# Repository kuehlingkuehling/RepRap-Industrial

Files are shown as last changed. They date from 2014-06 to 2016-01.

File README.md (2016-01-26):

# Kühling&Kühling RepRap Industrial

These are the OpenSCAD source files for the Kühling&Kühling RepRap Industrial 3D printer.
Based on the principle of the [RepRap Project](http://reprap.org) this 3D printer design is developed by

* Jonas Kühling <mail@jonaskuehling.de>
* Simon Kühling <mail@simonkuehling.de>

All information about the machine, build instructions and such will be published at
[http://kuehlingkuehling.de](http://kuehlingkuehling.de)
as soon as they are finished.

## Current Revision

1.4.1-dev

## License

This OpenSCAD code and its rendered 3D models are licensed unter the Creative Commons Attribution-ShareAlike 4.0 International License (CC BY-SA 4.0).
[https://creativecommons.org/licenses/by-sa/4.0/](https://creativecommons.org/licenses/by-sa/4.0/)

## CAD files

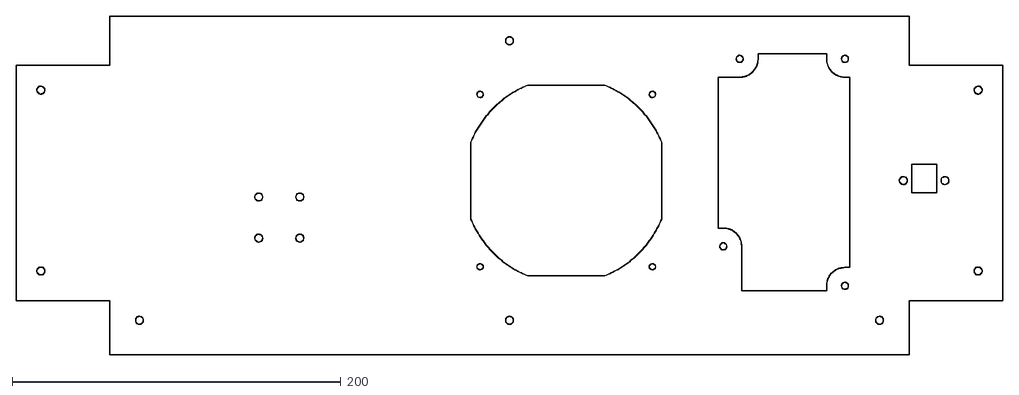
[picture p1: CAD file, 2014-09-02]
DXF/frame-enclosure_base-back.dxf
600.0 x 206.0

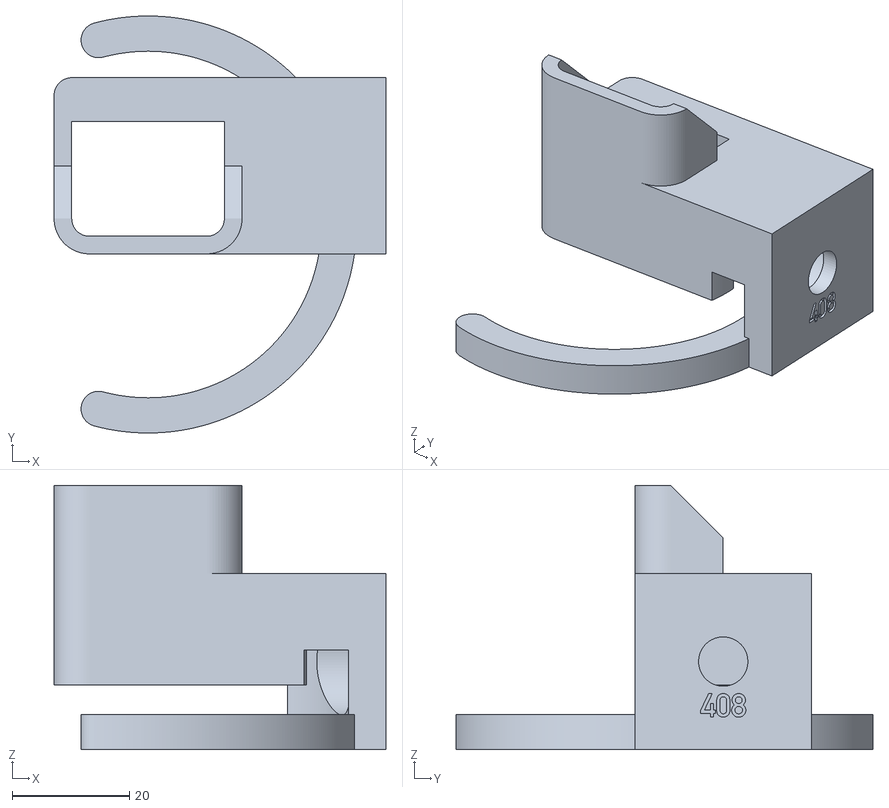
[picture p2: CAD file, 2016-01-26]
STL/408___wiper.stl
56.5 x 71.0 x 45.0

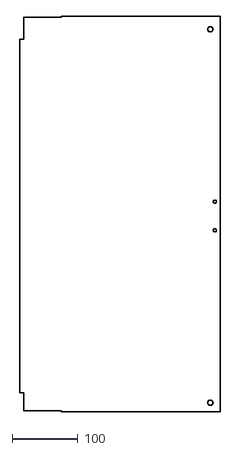
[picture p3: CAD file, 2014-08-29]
DXF/frame-enclosure_chamber-door-left.dxf
305.5 x 603.0

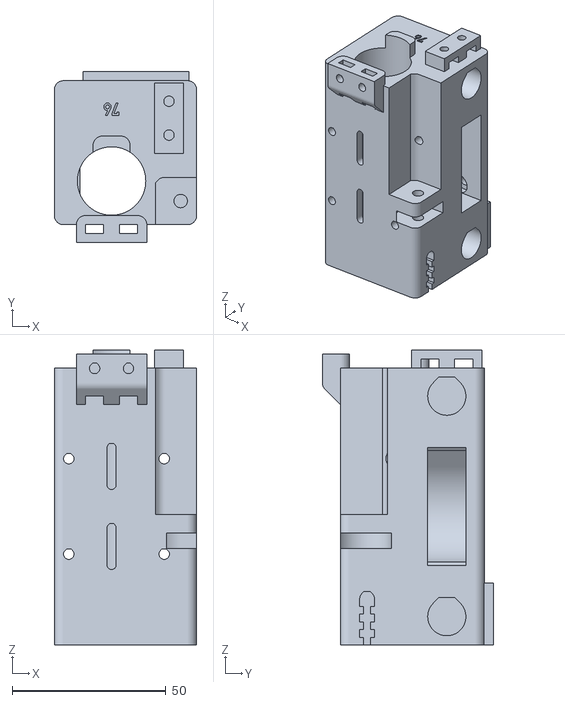
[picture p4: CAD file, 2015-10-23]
STL/76___x-end_motor.stl
46.2 x 55.6 x 95.8

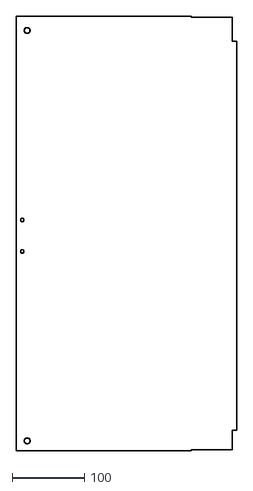
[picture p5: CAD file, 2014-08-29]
DXF/frame-enclosure_chamber-door-right.dxf
305.5 x 603.0

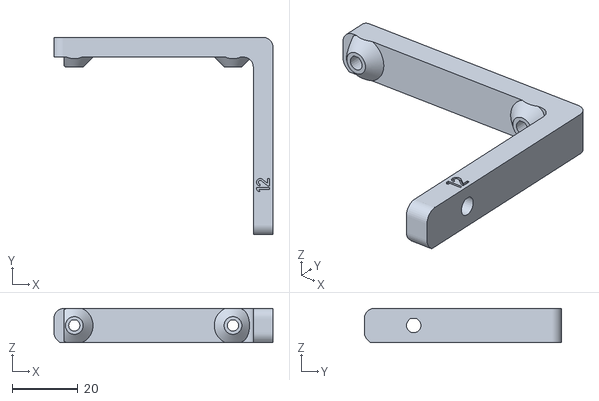
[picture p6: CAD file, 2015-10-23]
STL/12___pcb-mount_beagleboneblack-left.stl
66.6 x 60.0 x 10.4

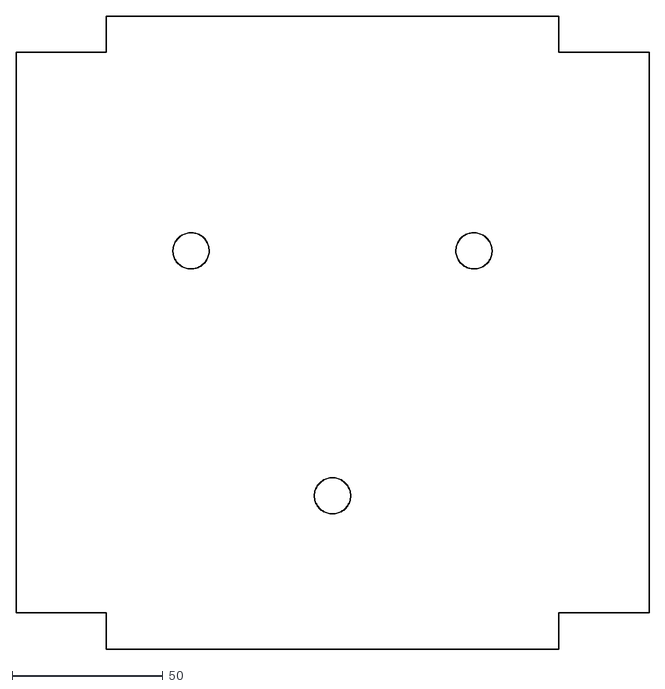
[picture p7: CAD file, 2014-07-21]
DXF/bed-siliconeheater.dxf
210.0 x 210.0

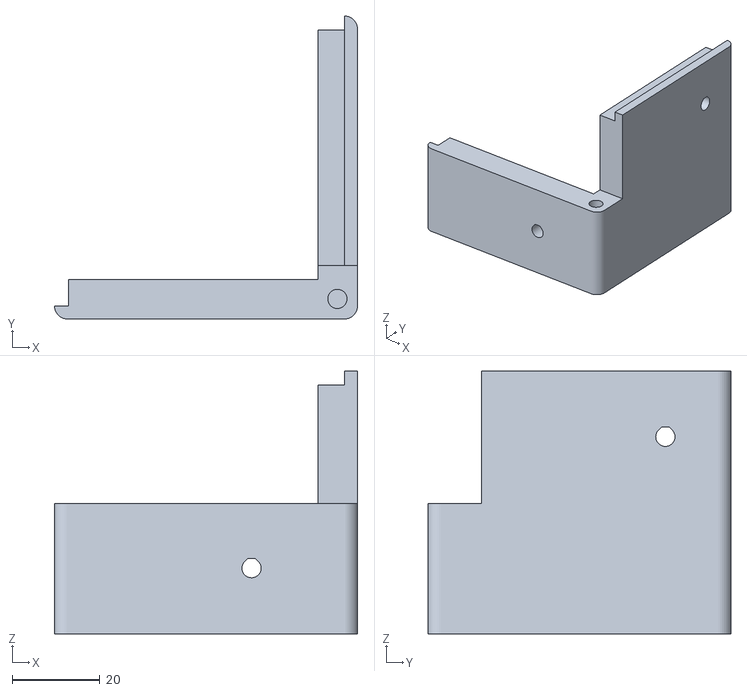
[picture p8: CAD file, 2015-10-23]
STL/48___frame-corner_middle-front-right.stl
69.2 x 69.2 x 60.0

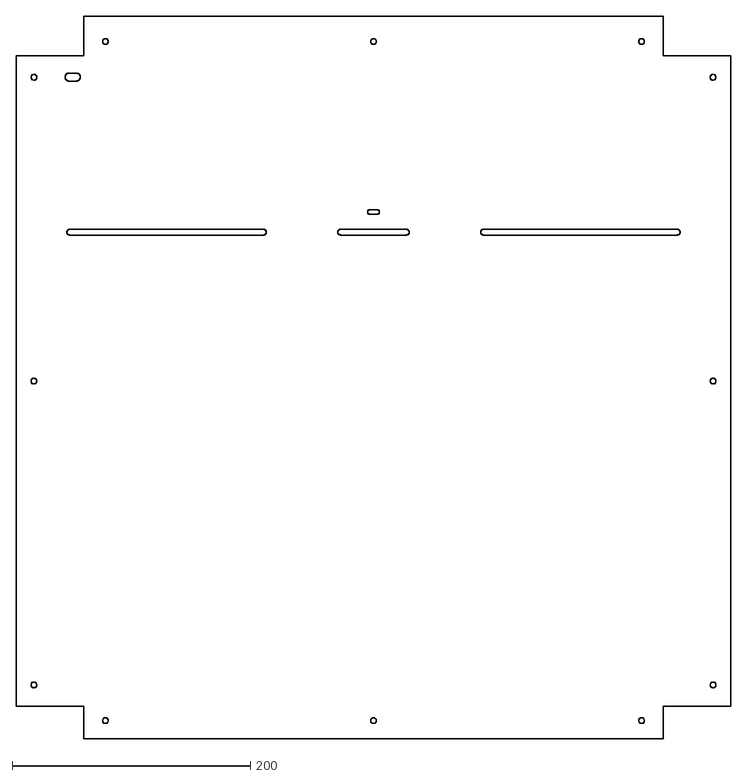
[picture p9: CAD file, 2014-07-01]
DXF/frame-enclosure_chamber-back.dxf
600.0 x 606.0

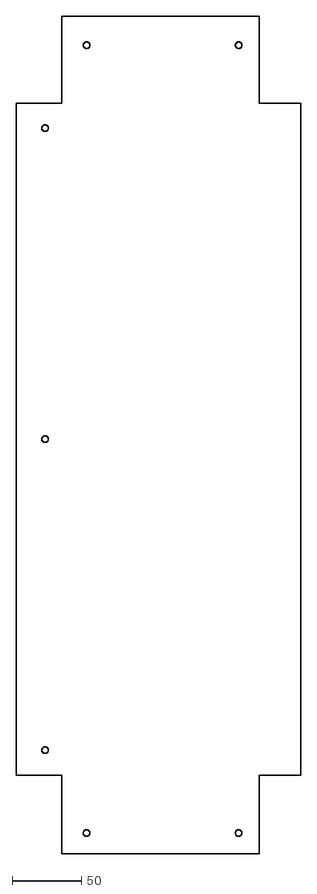
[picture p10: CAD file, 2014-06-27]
DXF/frame-enclosure_base-side.dxf
206.0 x 606.0

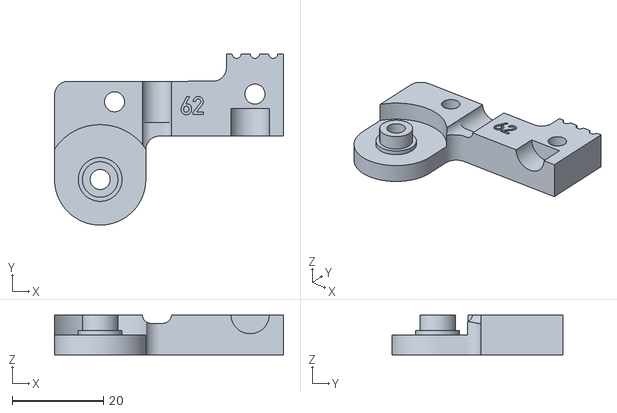
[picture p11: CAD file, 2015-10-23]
STL/62___extruder-idler_left-back.stl
50.1 x 37.5 x 8.75

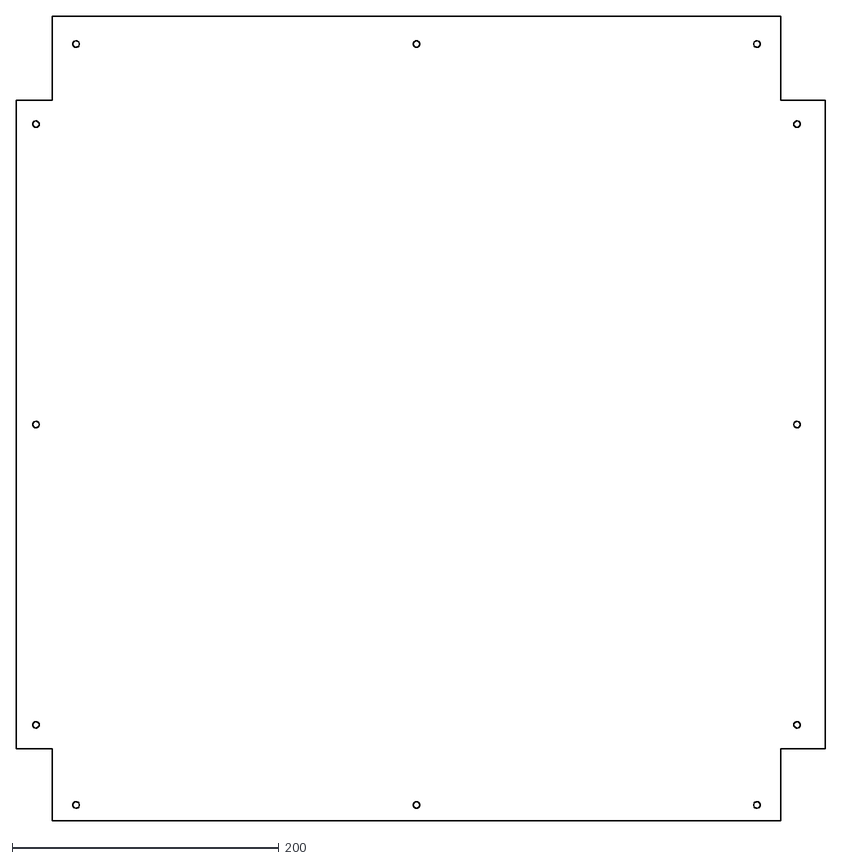
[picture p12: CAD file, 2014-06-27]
DXF/frame-enclosure_chamber-side.dxf
606.0 x 603.0

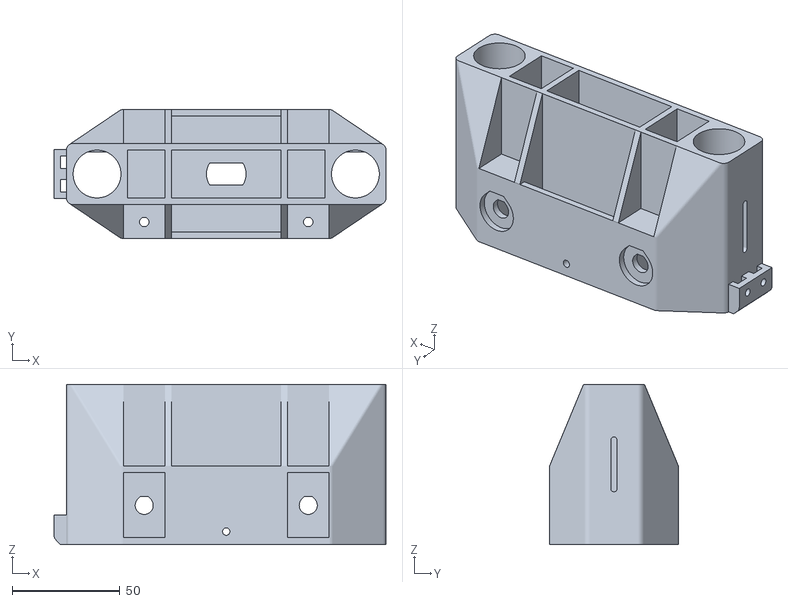
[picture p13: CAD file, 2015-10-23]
STL/39___z-elevator.stl
154.2 x 60.0 x 74.4

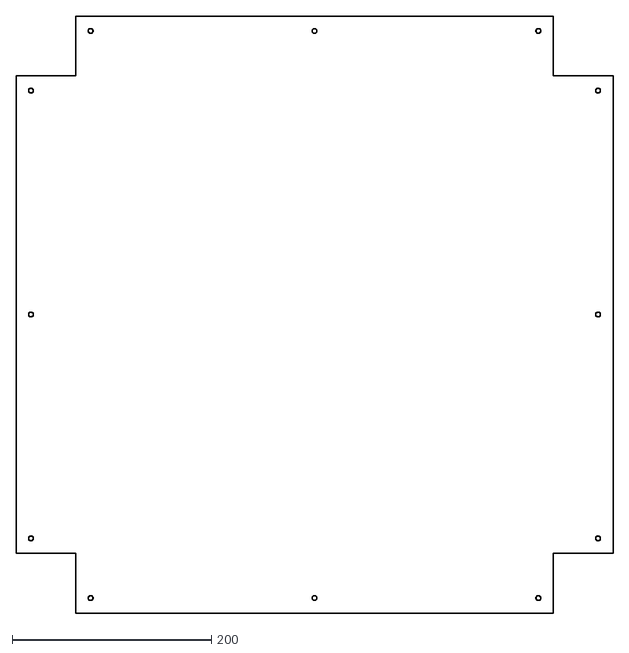
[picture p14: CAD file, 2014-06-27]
DXF/frame-enclosure_base-top.dxf
600.0 x 600.0

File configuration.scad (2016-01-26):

/*******************************************************************

This OpenSCAD code and its rendered 3D model are part of the

	Kühling&Kühling RepRap Industrial 3D Printer


All details, BOM, assembling instructions and latest sources:
	http://kuehlingkuehling.de

Designed and developed by:
	Jonas Kühling <mail@jonaskuehling.de>
	Simon Kühling <mail@simonkuehling.de>

License:
	Creative Commons Attribution-ShareAlike 4.0 International (CC BY-SA 4.0)
	https://creativecommons.org/licenses/by-sa/4.0/

*******************************************************************/

include <functions.scad>

///// PARAMETERS ////////////////////////////////////

$fa=1;
$fs=0.5;

support = false;				// set to "true" for FFF 3d printing (generates printability support layers etc.), leave "false" for SLS 3d printing

filament_dia = 2.85;
filament_tolerance = 0.1;		// +/-
filament_tube_dia = 6;			// inner dia: 4

m3_screw_dia = 3;						// M3
m3_screw_head_dia = 5.5;			// M3 inbus
m3_screw_head_length = 3;			// M3 inbus
m3_screw_lens_head_length = 1.65;		// M3 lens head screw
m3_nut_wrench = 5.5;				// M3
m3_nut_height = 2.4;				// M3
m3_squarenut_height = 1.8;		// M3 square nut flat
m3_washer_dia = 7;				// M3
m3_hex_wrench_dia = 3;			// allen key diameter

m4_screw_dia = 4;						// M4
m4_screw_head_dia = 7;				// M4 inbus
m4_screw_head_flange_dia = 9.4;	// M4 round head flange screw
m4_screw_head_length = 4;				// M4 inbus
m4_screw_head_wrench = 7;				// M4 hex head
m4_screw_head_wrench_length = 2.8;		// M4 hex head
m4_washer_dia = 9;				// M4
m4_washer_thickness = 0.8;		// M4
m4_nut_wrench = 7;				// M4
m4_nut_height = 3.2;				// M4
m4_locknut_height = 5;			// M4 locknut
m4_hex_wrench_dia = 3.5;			// allen key diameter
m4_flat_knurled_nut_dia = 16;
m4_flat_knurled_nut_height = 4;

m6_screw_dia = 6;
m6_nut_wrench = 10;
m6_nut_height = 5.2;

m8_screw_dia = 8;
m8_screw_head_wrench = 13;
m8_screw_head_wrench_length = 5.3;
m8_screw_roundheadflange_length = 4.4;			// round head flange screw
m8_nut_wrench = 13;
m8_nut_height = 6.5;
m8_washer_dia = 17.8;		// using larger dimension of round head flange screw head diameter here (m8 washer diameter: 16mm)
m8_washer_thickness = 1.6;

clearance = 0.2;				// for 3d printing; loose fit (screw holes etc.)
clearance_laser = 0.4;		// for laser cutting; gives 0.3mm actual clearance after laser cutting with 0.2mm cutting width
clearance_tight = 0.1;		// for 3d printing; tight/snug fit (bearings, bushings etc.)
layer_height = 0.24;
nozzle_dia = 0.35;

rod_dia = 12;
linear_bearing_dia = 22;					// LME12UU compatible
linear_bearing_length = 32;				// LME12UU compatible
linear_bearing_groove_width = 1.3;		// use fixation bolts of 1.3mm dia
linear_bearing_groove_dia = 20.5;
linear_bearing_groove_pos = 4.7;
linear_bearing_dist_min = 10;
wall = 3;
wall_thin = 1;

bearing_dia = 22;					// 608 bearing
bearing_width = 7;					// 608 bearing
bearing_center_dia = 8;				// 608 bearing
bearing_guide_dia = 28;

nema17_width = 43;
nema17_length = 48;
nema17_center_dia = 22;
nema17_center_pitch = 2;
nema17_hole_dist = 31;
nema17_screw_dia = m3_screw_dia;					// M3
nema17_screw_lens_head_length = m3_screw_lens_head_length;
nema17_screw_washer_dia = m3_washer_dia;			// M3
nema17_screw_hex_wrench_dia = m3_hex_wrench_dia;	// allen key diameter
//nema17_pulley_base = 8;
nema17_shaft_length = 25;
nema17_shaft_dia = 5;
nema17_gearbox_dia = 36;
nema17_gearbox_length = 28;
nema17_gearbox_center_dia = 22;
nema17_gearbox_center_pitch = 1.5;
nema17_gearbox_shaft_length = 20;		// distance mount flange surface - shaft end
nema17_gearbox_hole_pos_dia = 28;

frame_screw_dia = m4_screw_dia;
frame_screw_head_dia = m4_screw_head_dia;
frame_screw_head_length = m4_screw_head_length;
frame_screw_length = 10;
frame_screw_washer_dia = m4_washer_dia;
frame_screw_head_flange_dia = m4_screw_head_flange_dia;
frame_screw_washer_thickness = m4_washer_thickness;
frame_screw_nut_wrench = m4_nut_wrench;
frame_screw_nut_height = m4_nut_height;
frame_screw_hex_wrench_dia = m4_hex_wrench_dia;		// allen key diameter
frame_width = 30;						// t-slot B-type 30mm
frame_width_small = 19;				// t-slot B-type 19x30mm
frame_groove_width = 8;				// t-slot B-type 30mm
frame_groove_depth = 9;				// t-slot B-type 30mm
frame_groove_wall_thickness = 2.3;			// t-slot B-type 30mm
frame_center_screw_dia = m8_screw_dia;				// t-slot B-type 30mm
frame_center_screw_head_length = m8_screw_roundheadflange_length;
frame_center_screw_washer_dia = m8_washer_dia;				// t-slot B-type 30mm
frame_enclosure_thickness = 6;
frame_enclosure_door_hinge_bolt_dia = m4_screw_dia;
frame_enclosure_door_hinge_bolt_length = 36;
frame_base_dist = 170;					// space between lower horizontal frame bars (electronics enclosure)
frame_back_dist = 380;					// space between back horizontal frame bars (z-top to z-bottom)
frame_extrusion_length_horizontal = 540;
frame_extrusion_length_vertical = frame_width+frame_base_dist+frame_width+frame_extrusion_length_horizontal+frame_width;						// assembled frame height (vertical) = 800 (incl. cubic corner connectors)
frame_angle_side = 28;					// aluminum angles for t-slot
frame_door_handle_finger_clearance = 15;
frame_door_lock_magnet_dia = 8;
frame_cable_mount_zip_tie_width = 5.4;		// maximum zip tie width acceptance
frame_cable_mount_zip_tie_thickness = 2;		// maximum zip tie thickness acceptance

belt_width = 6;						// T2.5 belt, 6mm width
belt_thickness_min = 1;			// for T5: 1; for T2.5: 0.6
belt_thickness_max = 1+1.2;		// for T5: 1+1.2; for T2.5: 0.6+0.7
belt_tooth_periode = 5;			// T5: 5; T2.5: 2.5
belt_grip_length = 3;				// number of periodes; T5: 3; T2.5: 5
belt_tensioning_range = 15;
belt_tensioning_screw_dia = m4_screw_dia;
belt_tensioning_screw_head_dia = m4_screw_head_dia;
belt_tensioning_screw_head_wrench = m4_screw_head_wrench;		// hex head screw
belt_tensioning_screw_head_wrench_length = m4_screw_head_wrench_length;		// hex head screw
belt_tensioning_screw_head_length = m4_screw_head_length;
belt_tensioning_screw_length = 50;
belt_tensioning_washer_dia = m4_washer_dia;
belt_tensioning_washer_thickness = m4_washer_thickness;
belt_tensioning_nut_wrench = m4_nut_wrench;		// DEPRECATED in rev. 1.2.0, left for compatibility reasons
belt_tensioning_nut_height = m4_nut_height;		// DEPRECATED in rev. 1.2.0, left for compatibility reasons
belt_tensioning_knurled_nut_dia = m4_flat_knurled_nut_dia;
belt_tensioning_knurled_nut_height = m4_flat_knurled_nut_height;

belt_width_clearance = 0.5;
belt_pulley_retainer_width = 1;

endstop_height = 3;				// PCB thickness plus component clearance
endstop_hole_dist = 11;
endstop_hole_sensor_dist = 9;
endstop_screw_dia = m3_screw_dia;
endstop_screw_washer_dia = m3_washer_dia;
endstop_screw_nut_wrench = m3_nut_wrench;
endstop_screw_nut_height = m3_nut_height;
endstop_magnet_dia = 4;
endstop_magnet_length = 7;

bed_heatbed_thickness = 6.1;		// double faced corrugated aluminum sandwich
bed_heatbed_side = 212;
bed_heatbed_width = 212;            // introduced for temporary dev purpose in "bed_siliconeheater.scad" (bed_heatbed_side still in use elsewhere)
bed_heatbed_length = 212;           // introduced for temporary dev purpose in "bed_siliconeheater.scad" (bed_heatbed_side still in use elsewhere)
bed_siliconeheater_thickness = 3;
bed_siliconeheater_width = 210;
bed_siliconeheater_length = 210;
bed_surface_thickness = 1.5;		// PEI carbon fabric composite
bed_surface_side = 210;
bed_clamp_width = 12;				// foldback clamps 25mm, max. clamp width 9mm
bed_clamp_length = 25;				// foldback clamps 25mm, max. clamp width 9mm
bed_clamp_maxclampwidth = 12;
bed_clamp_angle_thickness = 3.5;
bed_clamp_angle_length = 14;
bed_leveling_mount_dia = 10;		// cylindrical glueing surfaces diameter for bonding to the aluminum sandwich
bed_leveling_rod_end_bearing_dia = 15;
bed_leveling_rod_end_bearing_width = 5;
bed_leveling_rod_end_bearing_screw_dia = m4_screw_dia;
bed_leveling_rod_end_bearing_screw_nut_wrench = m4_nut_wrench;
bed_leveling_rod_end_bearing_screw_nut_height = m4_nut_height;
bed_leveling_rod_end_bearing_shaft_wrench = 8;

air_heater_fan_side = 119;
air_heater_fan_dia = 125;
air_heater_fan_cutout_side = 116;
air_heater_fan_hole_dist = 104.8;
air_heater_fan_screw_dia = 5;			// hole for thermoplast screws grabbing into 4.5mm fan mount holes
air_heater_fan_screw_washer_dia = m4_washer_dia;
air_heater_uprofile_width = 120;
air_heater_uprofile_height = 40;
air_heater_uprofile_thickness = 3;
air_heater_cable_dia = 2;				// 2x2 AWG16
air_heater_overtemp_cable_dia = 1.25; // 2x1 AWG24
air_heater_mosfetboard_height = 15.45;
air_heater_mosfetboard_thickness = 1.7;
air_heater_heating_insert_height = 30;
air_heater_heating_insert_top_clearance = 30;
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

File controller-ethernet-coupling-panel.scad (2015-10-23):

/*******************************************************************

This OpenSCAD code and its rendered 3D model are part of the

	Kühling&Kühling RepRap Industrial 3D Printer


All details, BOM, assembling instructions and latest sources:
	http://kuehlingkuehling.de

Designed and developed by:
	Jonas Kühling <mail@jonaskuehling.de>
	Simon Kühling <mail@simonkuehling.de>

License:
	Creative Commons Attribution-ShareAlike 4.0 International (CC BY-SA 4.0)
	https://creativecommons.org/licenses/by-sa/4.0/

*******************************************************************/

include <configuration.scad>





// RENDERING
rotate([90,0,0])
    difference(){
        controller_ethernet_coupling_panel();
        translate([0,frame_enclosure_thickness+controller_ethernet_coupling_panel_body_length/2,0])
            label("29",orientation="bottom");
    }




module controller_ethernet_coupling_panel(){
	difference(){

		// main body
		hull(){
			translate([-controller_ethernet_coupling_panel_body_width/2+wall,frame_enclosure_thickness,wall])
				rotate([-90,0,0])
					cylinder(r=wall,h=controller_ethernet_coupling_panel_body_length);
			translate([controller_ethernet_coupling_panel_body_width/2-wall,frame_enclosure_thickness,wall])
				rotate([-90,0,0])
					cylinder(r=wall,h=controller_ethernet_coupling_panel_body_length);
			translate([-controller_ethernet_coupling_panel_body_width/2+wall,frame_enclosure_thickness,controller_ethernet_coupling_panel_body_height-wall])
				rotate([-90,0,0])
					cylinder(r=wall,h=controller_ethernet_coupling_panel_body_length);
			translate([controller_ethernet_coupling_panel_body_width/2-wall,frame_enclosure_thickness,controller_ethernet_coupling_panel_body_height-wall])
				rotate([-90,0,0])
					cylinder(r=wall,h=controller_ethernet_coupling_panel_body_length);
		}

		// controller ethernet coupling mount
		translate([-controller_ethernet_coupling_width_front/2-clearance,0,wall])
			cube([controller_ethernet_coupling_width_front+2*clearance,controller_ethernet_coupling_panel_front_dist,controller_ethernet_coupling_panel_body_height-2*wall]);
		translate([-controller_ethernet_coupling_width_front/2-clearance,0,2*wall])
			cube([controller_ethernet_coupling_width_front+2*clearance,frame_enclosure_thickness+controller_ethernet_coupling_panel_body_length+1,controller_ethernet_coupling_height_back+2*clearance]);
		translate([-controller_ethernet_coupling_width_back/2-clearance,controller_ethernet_coupling_panel_front_dist+controller_ethernet_coupling_panel_thickness,wall])
			cube([controller_ethernet_coupling_width_back+2*clearance,controller_ethernet_coupling_panel_front_dist,controller_ethernet_coupling_panel_body_height-2*wall]);

		// frame enclosure mount screw holes and nut traps
		for(i=[0,1])
			mirror([i,0,0]){
				translate([controller_ethernet_coupling_panel_body_width/2-wall-clearance-frame_screw_dia/2,0,controller_ethernet_coupling_panel_body_height/2])
					rotate([-90,0,0])
						cylinder(r=frame_screw_dia/2+clearance,h=frame_enclosure_thickness+controller_ethernet_coupling_panel_body_length+1);
				translate([controller_ethernet_coupling_panel_body_width/2-wall-clearance-frame_screw_dia/2,(frame_screw_nut_height+clearance+1)/2+frame_enclosure_thickness+wall,controller_ethernet_coupling_panel_body_height/2])
					rotate([0,180,0])
						rotate([-90,0,0])
							nut_slot_square(frame_screw_nut_wrench,frame_screw_nut_height,controller_ethernet_coupling_panel_body_width/2);
			}
	}
}

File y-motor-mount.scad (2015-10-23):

/*******************************************************************

This OpenSCAD code and its rendered 3D model are part of the

	Kühling&Kühling RepRap Industrial 3D Printer


All details, BOM, assembling instructions and latest sources:
	http://kuehlingkuehling.de

Designed and developed by:
	Jonas Kühling <mail@jonaskuehling.de>
	Simon Kühling <mail@simonkuehling.de>

License:
	Creative Commons Attribution-ShareAlike 4.0 International (CC BY-SA 4.0)
	https://creativecommons.org/licenses/by-sa/4.0/

*******************************************************************/

include <configuration.scad>




// RENDER
rotate([0,-90,0])
    difference(){
        y_motor_mount();
        translate([0,-(y_motor_mount_body_length-frame_width)/2,0])
            label("2",orientation="left");
    }




module y_motor_mount(){
	difference(){

		// main body
		translate([0,frame_width,-y_motor_mount_body_height+frame_width+wall])
			hull(){
				translate([0,-wall,y_motor_mount_body_height-wall])
					rotate([0,90,0])
						cylinder(r=wall,h=y_motor_mount_body_width);
				translate([0,-wall,wall])
					rotate([0,90,0])
						cylinder(r=wall,h=y_motor_mount_body_width);
				translate([0,-y_motor_mount_body_length+wall,y_motor_mount_body_height-wall])
					rotate([0,90,0])
						cylinder(r=wall,h=y_motor_mount_body_width);
				translate([0,-y_motor_mount_body_length+wall,wall])
					rotate([0,90,0])
						cylinder(r=wall,h=y_motor_mount_body_width);
			}

		// cut excess material
		translate([2*wall,0,-y_motor_mount_body_height+frame_width+wall])
			rotate([0,45,0])
				translate([0,-(y_motor_mount_body_length+2)+frame_width+1,-y_motor_mount_body_height])
					cube([y_motor_mount_body_height,y_motor_mount_body_length+2,2*y_motor_mount_body_height]);
			

		// frame clearance
		translate([-1,0,0])
			cube([y_motor_mount_body_width+2,frame_width+1,frame_width+wall+1]);

		// y motor belt tensioning thumbwheel and stud bolt clearance
		translate([wall+clearance+frame_screw_dia/2,frame_width/2,y_motor_mount_body_height/2-2*wall-1])
			rotate([0,90,0])
				teardrop(frame_screw_dia/2+clearance,y_motor_mount_body_height);
		hull(){
			translate([wall+clearance+frame_screw_dia/2,frame_width/2,(m4_flat_knurled_nut_height+1)/2-1-2*wall])
				rotate([0,90,0])
					teardrop(m4_flat_knurled_nut_dia/2+wall_thin,m4_flat_knurled_nut_height+1);
			translate([-wall,frame_width/2,(m4_flat_knurled_nut_height+1)/2-1-2*wall])
				rotate([0,90,0])
					teardrop(m4_flat_knurled_nut_dia/2+wall_thin,m4_flat_knurled_nut_height+1);
		}


		// nema17 mount
		translate([2*wall,-nema17_width+frame_width-wall,-nema17_width-2*wall])
			cube([y_motor_mount_body_width,nema17_width,nema17_width]);
		translate([-1,frame_width-wall-nema17_width/2,-nema17_width/2-2*wall])
			rotate([0,90,0])
				cylinder(r=nema17_center_dia/2+clearance,h=y_motor_mount_body_width+2);
		translate([-1,frame_width-wall-nema17_width/2,-nema17_width/2-2*wall])
			for(j=[0:3])
				rotate([j*90,0,0])
					translate([0,nema17_hole_dist/2,nema17_hole_dist/2])
						rotate([0,90,0])
							cylinder(r=nema17_screw_dia/2+clearance,h=y_motor_mount_body_width+2);

		// frame mount holes
		translate([y_motor_mount_body_width/2,0,0])
			for(i=[-1,1])
				translate([i*(y_motor_mount_body_width/2-(wall+clearance+frame_screw_head_flange_dia/2)),0,0]){
					hull(){
						translate([0,-y_motor_mount_body_length/2+frame_width,frame_width/2])
							rotate([0,0,90])
								rotate([90,0,0])
									teardrop(frame_screw_dia/2+clearance,y_motor_mount_body_length+2);
						translate([0,-y_motor_mount_body_length/2+frame_width,frame_width/2+2*wall+wall])
							rotate([0,0,90])
								rotate([90,0,0])
									teardrop(frame_screw_dia/2+clearance,y_motor_mount_body_length+2);
					}
					hull(){
						translate([0,-y_motor_mount_body_length/2-2*wall,frame_width/2])
							rotate([0,0,90])
								rotate([90,0,0])
									teardrop(frame_screw_head_flange_dia/2+clearance,y_motor_mount_body_length);
						translate([0,-y_motor_mount_body_length/2-2*wall,frame_width/2+2*wall+wall])
							rotate([0,0,90])
								rotate([90,0,0])
									teardrop(frame_screw_head_flange_dia/2+clearance,y_motor_mount_body_length);
					}
				}
	}
}

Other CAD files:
STL/8___frame-corner_middle-front-left.stl
STL/6___pcb-mount_beagleboneblack-right.stl
DXF/frame-enclosure_base-bottom.dxf
STL/18___air-filter_activatedcarbon-container-lid.stl
z-motor-mount.scad
DXF/frame-enclosure_base-front.dxf
DXF/frame-enclosure_chamber-top.dxf
STL/10___extruder-idler_left-front.stl
STL/13___frame-enclosure-door-handle.stl
STL/14___frame-small-mount.stl
STL/16___frame-corner_door-bottom-right.stl
STL/17___belt-tensioner_y-right_x.stl
STL/20___air-filter_activatedcarbon-container.stl
STL/22___extruder-front.stl
STL/23___z-end_top.stl
STL/24___z-end_bottom.stl
STL/25___pcb-mount_rumba-left.stl
STL/264___filament-feed.stl
STL/268___y-endstop-magnet-mount.stl
STL/26___z-bed-mount.stl
STL/275___frame-enclosure-cable-feedthrough_10.stl
STL/277___frame-enclosure-cable-feedthrough_20.stl
STL/27___spool-mount-endcap.stl
STL/289___led-mount_left.stl
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

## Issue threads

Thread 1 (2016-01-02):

Can't find the bed stl's

visualinventor, 2016-01-02:
I am really liking your design for the bed cantilever but I can't seem to get the bed stls to match up with the pictures of the machine.

I see:
23 - z_end_top that = seems to be related to the 12mm vertical rods for the bed
26 - z_bedmount = this seems to be part of the bed cantilever
351 - bed_level_mounting = I dont see this in the parts of the pictures at all
39 - z_elevator = this seems like a part I see in the pics (albeit different).

So where are the screw leveler tighteners, the small spacer in the front of the bed arms that keep the bed arms parallel (it's kind of spider web shaped).

Also you might label these parts with leading zeros so they group properly.
Like so: "23 - z_end_top" would become "023 - z_end_top"

Thanks for any help you can give.

visualinventor, 2016-01-02:
This is the image I'm referencing.
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

simonkuehling, 2016-01-04:
Dear Tim,

the picture you reference show the last complete prototype of the RepRap
Industrial before moving forward into actual production. There has been
a lot of design for manufacturing and refactoring between the prototype
and our first stable release of hardware revision 1.0.0.
Since this prototype was only built once and never manufactured, there
is no complete BOM and documentation i can provide.

Anyway, the OpenSCAD design source files can be found in the initial
commit to this repository:
https://github.com/kuehlingkuehling/RepRap-Industrial/tree/21617c75c6598705de657237b02d8eea059c1118
The part you are looking for is programmed in z-bedclamp-front.scad
More pictures of the prototype are archived at
http://docs.kuehlingkuehling.de/reprap-industrial-v0/overview

If you are however looking for the STLs of any hardware revision from
1.0.0 onwards, you find the full set of BOM/partslist/STLs/DXF for
download in the github releases. These are the sources of our machines
manufactured from late 2013 on:
https://github.com/kuehlingkuehling/RepRap-Industrial/releases
The up-to-date Manual can be found here as well:
http://docs.kuehlingkuehling.de/

Please get back to me if i can provide further help or clarification.

Regards
Simon Kühling

Simon Kühling, CEO/Co-Founder
simon@kuehlingkuehling.de
+49 (0) 431 98 35 24 73 - 11

Kühling&Kühling GbR

Postal Address
Im Wiesengrund 23, 24113 Molfsee, Germany

Office/Factory
Christianspries 30, 24159 Kiel, Germany

Phone +49 (0) 431 98 35 24 73 - 0
Fax +49 (0) 431 98 35 24 16
E-Mail office@kuehlingkuehling.de
Web http://kuehlingkuehling.de
VAT Reg.No. DE283006938

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

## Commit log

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2014-06-17 add missing files accidentally not included in last release
    [air-heater-bottom.scad, air-heater-front.scad, air-heater-mosfetboard-mount.scad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]
2014-06-27 change air heater design to new compact resistor wire based heating inserts
    [air-heater-bottom.scad, air-heater-front.scad, air-heater-top.scad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]
2014-06-27 change heatbed design and bed leveling for new aluminum sandwich plate with custom silicon heating panel
    [bed-bottom.scad, bed-corner.scad, bed-leveling-mount.scad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]
2014-06-27 adjust miscellaneous dimensions for better fit
    [controller-ethernet-coupling-panel.scad, frame-corner.scad, frame-enclosure.scad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]
2014-06-27 replace printed set collars with steel clamp collars
    [set-collar.scad, z-end.scad]
2014-06-27 provide rendered STLs and DXFs of latest dev revision
    [air-filter_activatedcarbon-container-lid.stl, air-filter_activatedcarbon-container.stl, air-filter_fan-duct.stl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]
2014-06-27 introduce "clearance_tight" parameter for snug fittings (bearings, bushings, smooth rods)
    [x-carriage.scad, x-carriage.stl, x-end.scad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]
2014-06-27 add extra depth for x end x rod holes
    [x-end.scad, x-end_idler.stl, x-end_motor.stl]
2014-06-27 apply "clearance_tight" to z ends, y ends; further minor adjustments to y ends
    [y-end.scad, y-end_back-left.stl, y-end_back-right.stl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]
2014-06-27 introduce optional printability support for FFF 3d printing; can be turned off for e.g. SLS 3d printing
    [air-filter.scad, air-filter_fan-duct.stl, configuration.scad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]
2014-06-27 adjust air filter activated carbon container grid spacing
    [air-filter_activatedcarbon-container-lid.stl, air-filter_activatedcarbon-container.stl, configuration.scad]
2014-06-27 remove extruder-iler-hinge-washer; replaced by two standard M4 nylon washers
    [extruder-idler.scad, extruder-idler_hinge-washer.stl]
2014-06-27 apply clearance_tight to extruder idler bearing shaft
    [extruder-idler.scad, extruder-idler_left-back.stl, extruder-idler_left-front.stl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]
2014-06-27 apply clearance_tight to y belt arbor support bearing trap
    [y-arbor-support.scad, y-arbor-support_top.stl]
2014-06-30 adjust dimensions for new extruder planetary geared stepper motors and new endstop pcbs plus dependent screw lengths
    [configuration.scad, extruder-back.scad, extruder-back.stl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]
2014-07-01 modify chamber door lock magnet diameter
    [configuration.scad, frame-enclosure.scad, frame-enclosure_chamber-door-left.dxf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]
2014-07-01 replace cablechains with IGUS parts; merge x-cablechain-mount into extruder-back
    [cablechain-mount-extruder.scad, cablechain-mount-extruder.stl, cablechain.scad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]
2014-07-07 adjust extruder stepper motor gearbox dimensions
    [configuration.scad]
2014-07-09 adjust print bed thickness
    [bed-corner_front-left_back-right.stl, bed-corner_front-right_back-left.stl, configuration.scad]
2014-07-14 add letter marking to avoid confusion with similar parts
    [bed-corner.scad, bed-corner_front-left_back-right.stl, bed-corner_front-right_back-left.stl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]
2014-07-15 modify z_end_body_length to account for new set collar dimensions
    [configuration.scad, z-end.scad]
2014-07-15 add more letter marking for z ends
    [z-end.scad, z-end_bottom.stl, z-end_top.stl]
2014-07-15 adjust MOSFET board mount for better fit
    [air-heater-mosfetboard-mount.scad, air-heater-mosfetboard-mount.stl]
2014-07-15 provide better fit for HDMI-LVDS controller board
    [controller-touchscreen-adapterpcb-mount.scad, controller-touchscreen-adapterpcb-mount.stl]
2014-07-15 adjust touchscreen dimensions for new display panels; code beautification
    [configuration.scad, controller-touchscreen-housing-back.dxf, controller-touchscreen-housing-back.scad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]
2014-07-21 add new custom silicon heating panel, provide DXF cut file for silicone outline
    [bed-siliconeheater.dxf, bed-siliconeheater.scad, configuration.scad]
2014-08-04 adjust extruder idler bearing fit to avoid tilting
    [extruder-idler.scad, extruder-idler_left-back.stl, extruder-idler_left-front.stl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]
2014-08-15 update x-carriage STL export, previously missed after SCAD modifications
    [x-carriage.stl]
2014-08-19 adjust y belt idler pulley clearance, substitute printed flange by two M8 washers
    [configuration.scad, y-end.scad, y-end_front-left.stl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]
2014-08-21 fix y rod clamp clearance (use new clearance_tight parameter)
    [configuration.scad, y-endstop-magnet-mount.scad, y-endstop-magnet-mount.stl]
2014-08-21 fix y endstop position after recent changes in code
    [y-endstop-magnet-mount.scad, y-endstop-magnet-mount.stl]
2014-08-29 remove screws in favor of glueing; makes for less adjustment effort of chamber doors/hinges
    [frame-corner.scad, frame-corner_door-bottom-left.stl, frame-corner_door-bottom-right.stl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]
2014-09-02 drop linear bearing fixation nail holes in favor of glueing
    [x-carriage.scad, x-carriage.stl, x-end.scad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]
2014-09-02 add extra space between waterpump and radiator to enable easier hose connection
    [frame-enclosure.scad, frame-enclosure_base-back.dxf]
2014-10-15 add teflon liner to filament feed entry to significantly reduce occasional filament friction
    [filament-feed.scad, filament-feed.stl]
2014-11-11 add center marking on z-ends for easier positioning during machine assembly
    [z-end.scad, z-end_bottom.stl, z-end_top.stl]
2015-01-15 drop printed frame-cable-clips in favor of quality PA self-adhesive zip tie sockets and PA zip ties
    [frame-cable-clip.scad, frame-cable-clip_10.stl, frame-cable-clip_15.stl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]
2015-01-16 drop printed thumb wheels in favor of DIN 467 flat knurled nuts
    [configuration.scad, x-carriage.scad, x-carriage.stl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]
2015-01-16 modify hotend wire fixation solution underneath x carriage; use zip ties now
    [configuration.scad, x-carriage.scad, x-carriage.stl]
2015-01-16 remove thumbwheel SCAD/STL in reference to earlier commit b440afbb46742bacd6149bcbe872488c9eb2d833
    [thumbwheel.scad, thumbwheel.stl]
2015-01-21 introduce slot hole in z-motor-mount for z axis spindle drive belt tensioning
    [z-motor-mount.scad, z-motor-mount.stl]
2015-01-21 correct pulley clearance diameter in z-motor-mount
    [z-motor-mount.scad, z-motor-mount.stl]
2015-01-22 re-introduce y motor belt tensioning solution via thumbwheel/stud bolt
    [configuration.scad, y-motor-mount.scad, y-motor-mount.stl]
2015-01-22 drop printed pulleys in favor of custom aluminum substitutes
    [pulley.scad, pulley_x-motor.stl, pulley_y-arbor-left.stl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]
2015-01-23 add hot end water cooler clearance to x-carriage
    [configuration.scad, x-carriage.scad, x-carriage.stl]
2015-01-29 adjust touchscreen dimensions for new universal HDMI touch display panel compatibility
    [configuration.scad, controller-touchscreen-adapterpcb-mount.scad, controller-touchscreen-adapterpcb-mount.stl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]
2015-02-20 add optional experimental extruder adapter piece for printing flexible filaments like TPEs
    [extruder-flexible-filament-adapter.scad, extruder-flexible-filament-adapter_left.stl, extruder-flexible-filament-adapter_right.stl]
2015-04-28 adjust touchpanel backside hdmi cable clearance
    [configuration.scad, controller-touchscreen-housing-frame.stl]
2015-07-15 introduce print head nozzle wiper
    [configuration.scad, functions.scad, wiper.scad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]
2015-10-19 minor fix referring to changes from commit #68af8d
    [bed-leveling-mount.scad, bed-leveling-mount.stl]
2015-10-19 dropping MOSFET boards in favor of solid state relays
    [air-heater-mosfetboard-mount.scad, air-heater-mosfetboard-mount.stl]
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2016-01-26 introduce custom aluminum print bed sandwich, replace corrugated aluminum sandwich
    [bed-heatbed.scad, bed-siliconeheater.scad, configuration.scad]
2016-01-26 introduce single extruder setup for model HT500 S300200
    [extruder-back_single.scad, extruder-front_single.scad]
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2016-01-26 account for touch screen monitor replacement, new fully encased model
    [30___controller-touchscreen-housing-mount.stl, 50___controller-touchscreen-housing-frame.stl, controller-touchscreen-housing-back.dxf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]
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2016-01-26 replace back right chamber cable feed-through with 20mm version, remove 15mm STL
    [276___frame-enclosure-cable-feedthrough_15.stl, frame-enclosure-cable-feedthrough.scad]
